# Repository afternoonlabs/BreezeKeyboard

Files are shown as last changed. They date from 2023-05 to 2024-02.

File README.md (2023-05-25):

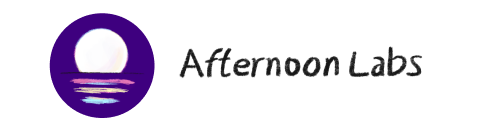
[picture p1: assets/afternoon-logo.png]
Afternoon Labs Logo


# Breeze

> Ergonomics meets Productivity.

## Introduction

"Breeze" is a split mechanical keyboard with a column-staggered layout. With a focus on productivity, Breeze features a full 6x4 alphanumeric layout, arrow keys, and an extra 6 key cluster for typing and coding.

Learn more at: [www.afternoonlabs.com](https://www.afternoonlabs.com)

## Features

* Split Ergonomics
* Productivity Cluster for Typing and Coding
* Open-source PCB design for easy modifications
* Hotswap MX or Choc Sockets
* Option to Manufacture with Diodes Built-in, No Diode Soldering Required
* Columnar Stagger
* Arrow Keys!
* QMK, Pro Micro, VIA Compatible
* Bonus 6 Key or 9 Key Macro Pad Included (The **Gust** Macro Pad)

## Getting Started

These instructions will guide you on how to replicate this keyboard design on your local machine for development, testing, or personal use.

For instructions for assembly of a Breeze keyboard once you have a PCB, follow [the official build guide](https://www.afternoonlabs.com/breeze/build-guide).

### Prerequisites

Before starting, make sure you have:

* KiCad 6 or later installed
* Basic understanding of electronic circuit design
* Basic understanding of mechanical keyboard assembly

### Installation

Follow these steps to get a copy of the project up and running:

1. Clone the repository

```bash
git clone https://github.com/afternoonlabs/BreezeKeyboard
```

2. Open the project `Breeze.kicad_pro` file with KiCad

3. Now, you can view, edit, and export the schematic and PCB layout for manufacturing.

## Support us

Enjoying the Breeze? [Buy me a beer](https://www.buymeacoffee.com/Afternoonlabs).

## Contribution

Contributions are encouraged! Whether it's bug fixes, new features, or even simple feedback, everything helps in making the project better.

1. Fork the Project
2. Create your Feature Branch (`git checkout -b feature/SomeFeature`)
3. Commit your Changes (`git commit -m 'Adding SomeFeature'`)
4. Push to the Branch (`git push origin feature/SomeFeature`)
5. Open a Pull Request

## License

Anyone can use this project for personal use. Distributed under the MIT License. See `LICENSE` for more information.

Vendors interested in selling the Breeze, please contact us below.

The use of "Afternoon Labs" is protected under copyright law. Unauthorized use without express permission from "Afternoon Labs", is prohibited.

## Contact

Join our [Discord Server](https://discord.gg/9nsApe3GvG).

Afternoon Labs - [hi@afternoonlabs.com](mailto:hi@afternoonlabs.com)

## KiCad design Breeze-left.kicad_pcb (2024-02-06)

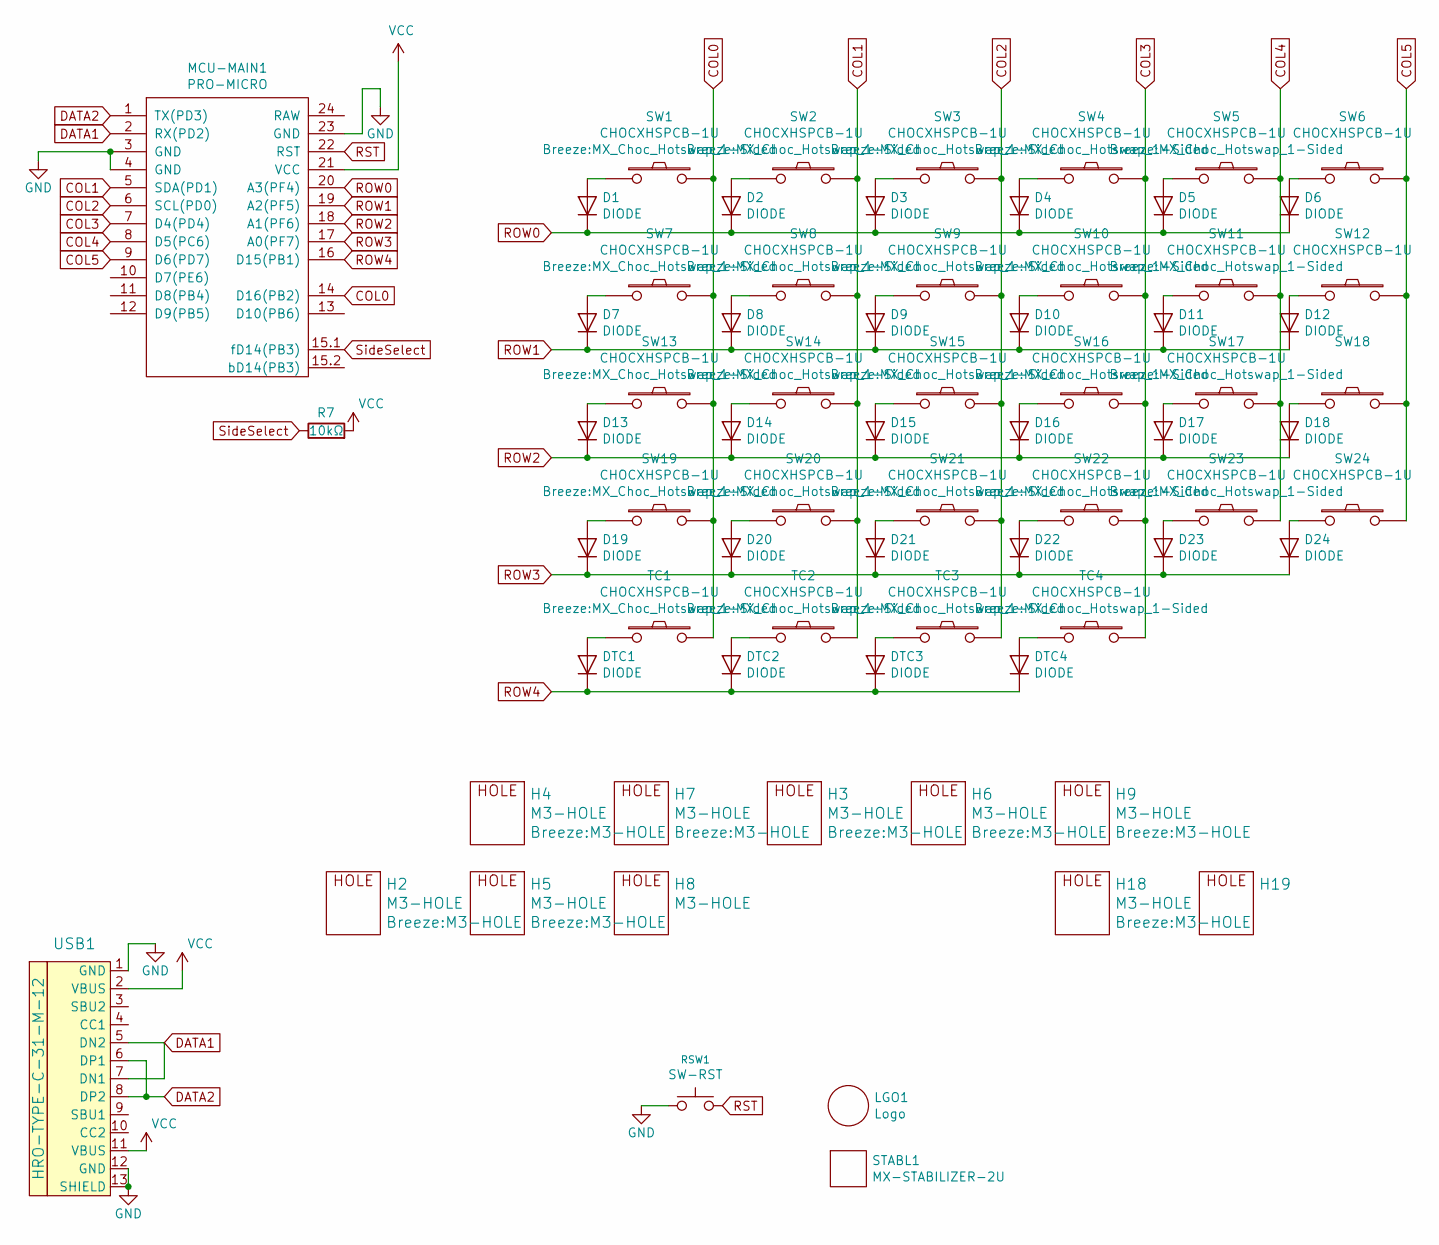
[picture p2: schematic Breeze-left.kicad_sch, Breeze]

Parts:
D1, D2, D3, D4, D5, D6, D7, D8, D9, D10, D11, D12, D13, D14, D15, D16, D17, D18, D19, D20, D21, D22, D23, D24: DIODE; SOD-123FL; LCSC C64898
DTC1, DTC2, DTC3, DTC4: DIODE; SOD-123FL; LCSC C64898
H2, H3, H4, H5, H6, H7, H8, H9, H18, H19: M3-HOLE
LGO1: Logo; logo
MCU-MAIN1: PRO-MICRO; ProMicro_1-Sided
R7: 10kΩ; R_0603_1608Metric
RSW1: SW-RST; SW_SPST_TL3342
STABL1: MX-STABILIZER-2U; Stabilizer_MX_2u
SW1, SW2, SW3, SW4, SW5, SW6, SW7, SW8, SW9, SW10, SW11, SW12, SW13, SW14, SW15, SW16, SW17, SW18, SW19, SW20, SW21, SW22, SW23, SW24: CHOCXHSPCB-1U; MX_Choc_Hotswap_1-Sided
TC1, TC2, TC3, TC4: CHOCXHSPCB-1U; MX_Choc_Hotswap_1-Sided
USB1: HRO-TYPE-C-31-M-12; USB-C-12-Pin-MidMount

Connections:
COL0: MCU-MAIN1.14 (D16(PB2)), SW1.2, SW7.2, SW13.2, SW19.2, TC1.2
COL1: MCU-MAIN1.5 (SDA(PD1)), SW2.2, SW8.2, SW14.2, SW20.2, TC2.2
COL2: MCU-MAIN1.6 (SCL(PD0)), SW3.2, SW9.2, SW15.2, SW21.2, TC3.2
COL3: MCU-MAIN1.7 (D4(PD4)), SW4.2, SW10.2, SW16.2, SW22.2, TC4.2
COL4: MCU-MAIN1.8 (D5(PC6)), SW5.2, SW11.2, SW17.2, SW23.2
COL5: MCU-MAIN1.9 (D6(PD7)), SW6.2, SW12.2, SW18.2, SW24.2
DATA1: MCU-MAIN1.2 (RX(PD2)), USB1.5 (DN2), USB1.7 (DN1)
DATA2: MCU-MAIN1.1 (TX(PD3)), USB1.6 (DP1), USB1.8 (DP2)
GND: MCU-MAIN1.3 (GND), MCU-MAIN1.4 (GND), MCU-MAIN1.23 (GND), RSW1.1, USB1.1 (GND), USB1.12 (GND), USB1.13 (SHIELD)
unnamed: D1.2 (A), SW1.1
unnamed: D2.2 (A), SW2.1
unnamed: D3.2 (A), SW3.1
unnamed: D4.2 (A), SW4.1
unnamed: D5.2 (A), SW5.1
unnamed: D6.2 (A), SW6.1
unnamed: D7.2 (A), SW7.1
unnamed: D8.2 (A), SW8.1
unnamed: D9.2 (A), SW9.1
unnamed: D10.2 (A), SW10.1
unnamed: D11.2 (A), SW11.1
unnamed: D12.2 (A), SW12.1
unnamed: D13.2 (A), SW13.1
unnamed: D14.2 (A), SW14.1
unnamed: D15.2 (A), SW15.1
unnamed: D16.2 (A), SW16.1
unnamed: D17.2 (A), SW17.1
unnamed: D18.2 (A), SW18.1
unnamed: D19.2 (A), SW19.1
unnamed: D20.2 (A), SW20.1
unnamed: D21.2 (A), SW21.1
unnamed: D22.2 (A), SW22.1
unnamed: D23.2 (A), SW23.1
unnamed: D24.2 (A), SW24.1
unnamed: DTC1.2 (A), TC1.1
unnamed: DTC2.2 (A), TC2.1
unnamed: DTC3.2 (A), TC3.1
unnamed: DTC4.2 (A), TC4.1
ROW0: D1.1 (K), D2.1 (K), D3.1 (K), D4.1 (K), D5.1 (K), D6.1 (K), MCU-MAIN1.20 (A3(PF4))
ROW1: D7.1 (K), D8.1 (K), D9.1 (K), D10.1 (K), D11.1 (K), D12.1 (K), MCU-MAIN1.19 (A2(PF5))
ROW2: D13.1 (K), D14.1 (K), D15.1 (K), D16.1 (K), D17.1 (K), D18.1 (K), MCU-MAIN1.18 (A1(PF6))
ROW3: D19.1 (K), D20.1 (K), D21.1 (K), D22.1 (K), D23.1 (K), D24.1 (K), MCU-MAIN1.17 (A0(PF7))
ROW4: DTC1.1 (K), DTC2.1 (K), DTC3.1 (K), DTC4.1 (K), MCU-MAIN1.16 (D15(PB1))
RST: MCU-MAIN1.22 (RST), RSW1.2
SideSelect: MCU-MAIN1.15.1 (fD14(PB3)); also elsewhere on the board
VCC: MCU-MAIN1.21 (VCC), USB1.2 (VBUS), USB1.11 (VBUS); also elsewhere on the board

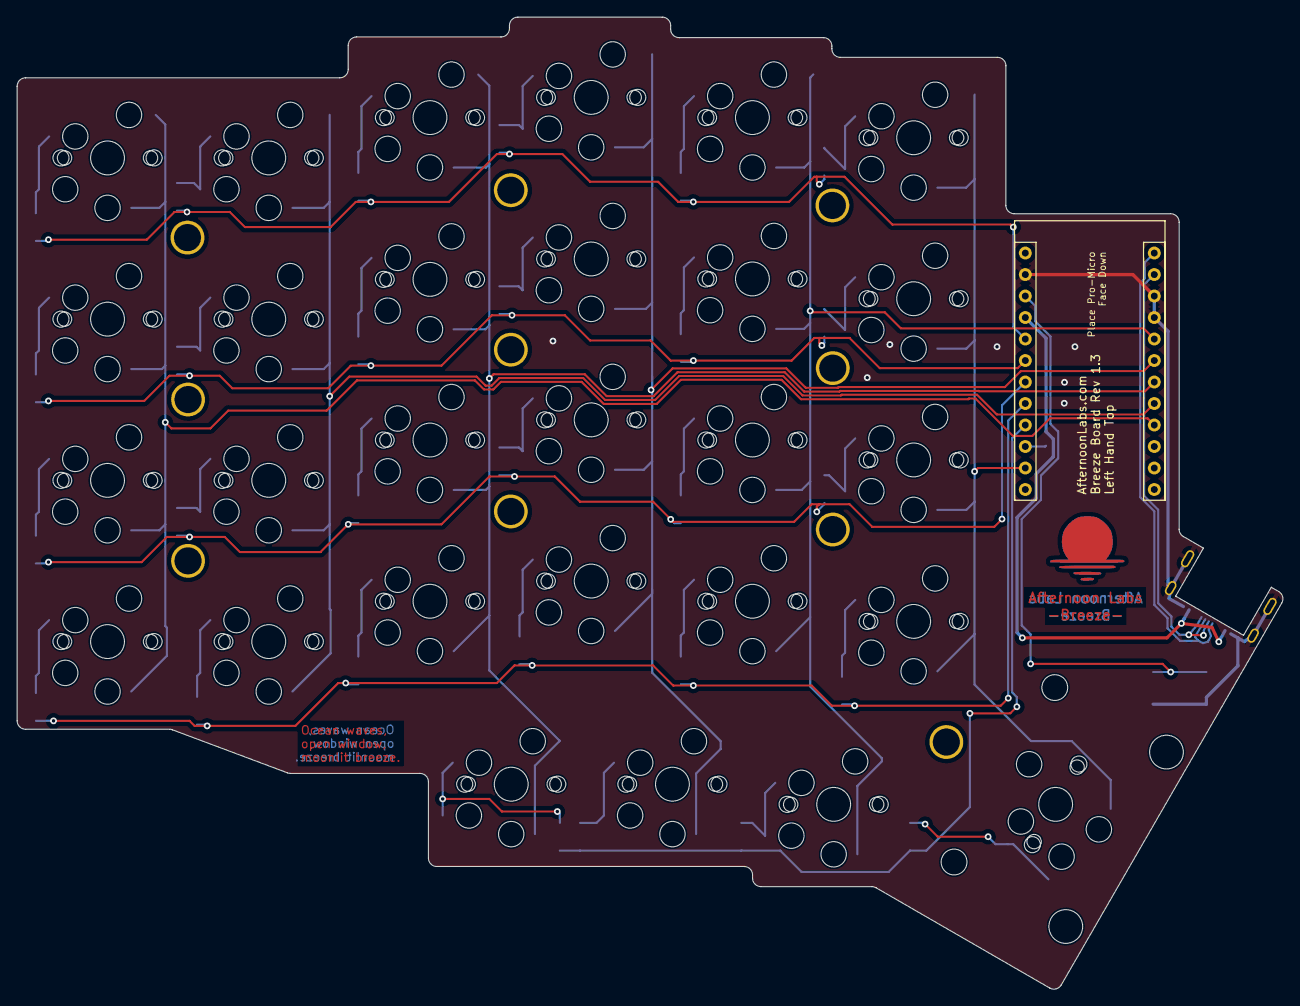
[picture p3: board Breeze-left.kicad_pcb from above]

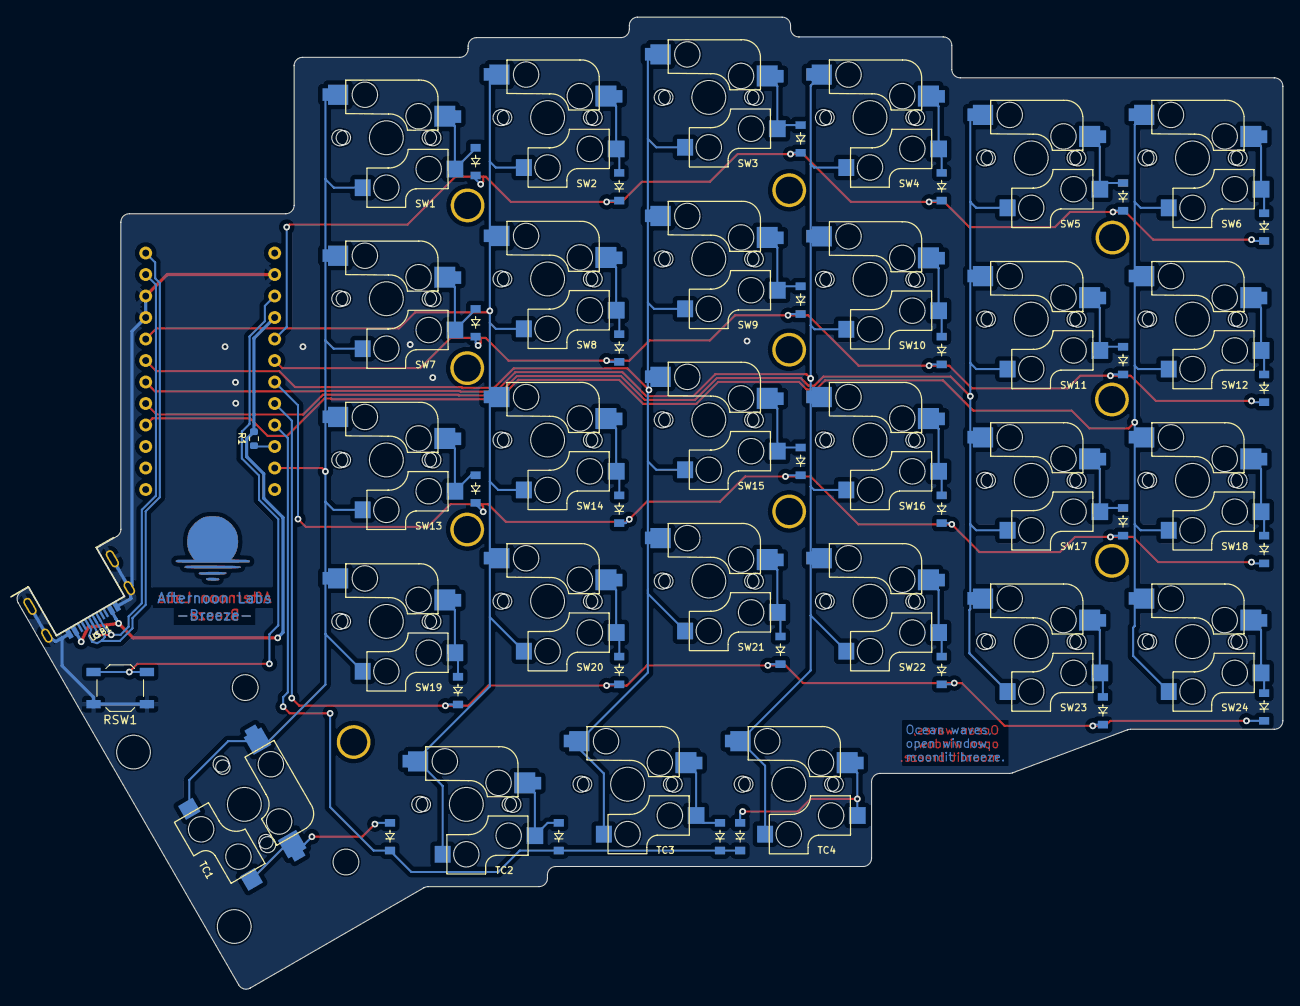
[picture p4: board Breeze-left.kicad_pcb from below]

Board: 2 copper layers, 149.6 x 114.9 mm, 72 parts (43 on the bottom side), 45 nets.

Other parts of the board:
R1: 10kΩ; R_0603_1608Metric

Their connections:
SideSelect: R1.1; also elsewhere on the board
VCC: R1.2; also elsewhere on the board

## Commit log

2023-05-21 Open sourcing :)
    [Breeze.kicad_pcb, Breeze.kicad_sch, Breeze.sch]
2023-08-28 Update KiCAD format
    [Breeze.kicad_pcb, Breeze.kicad_sch, Breeze.sch]
2023-08-28 Switch interconnect TRRS to USB-C, change to SMD reset button (rerouting of traces not done)
    [Breeze.kicad_pcb, Breeze.kicad_sch]
2023-08-28 Fork design off into left and right halves
    [Breeze-left.kicad_pcb, Breeze-left.kicad_sch, Breeze-right.kicad_pcb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]
2023-08-29 Add 1-sided Pro Micro and socket footprints, add USB-C mid-mount, add 3D models
2023-08-29 Move diodes to bottom side, switch to single-sided Pro Micro and sockets
    [Breeze-right.kicad_pcb, Breeze-right.kicad_sch]
2023-08-29 Copy right half to left
    [Breeze-left.kicad_pcb, Breeze-left.kicad_sch]
2023-08-29 Set side select config for left half
    [Breeze-left.kicad_sch]
2023-09-01 Remove stray line on silkscreen
2023-09-01 Remove extra holes and switches for breakoff portion on left half
    [Breeze-left.kicad_sch]
2023-09-01 Route left hal
    [Breeze-left.kicad_pcb]
2023-09-01 Update switch footprint to fix silkscreen lines
    [Breeze-right.kicad_pcb]
